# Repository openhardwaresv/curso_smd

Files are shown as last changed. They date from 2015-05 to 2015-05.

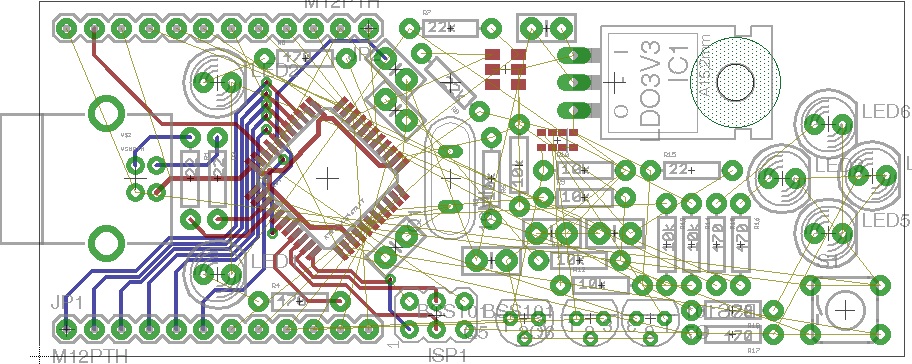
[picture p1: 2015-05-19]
dsn/auxiliar/Sensorino_PTH.jpg

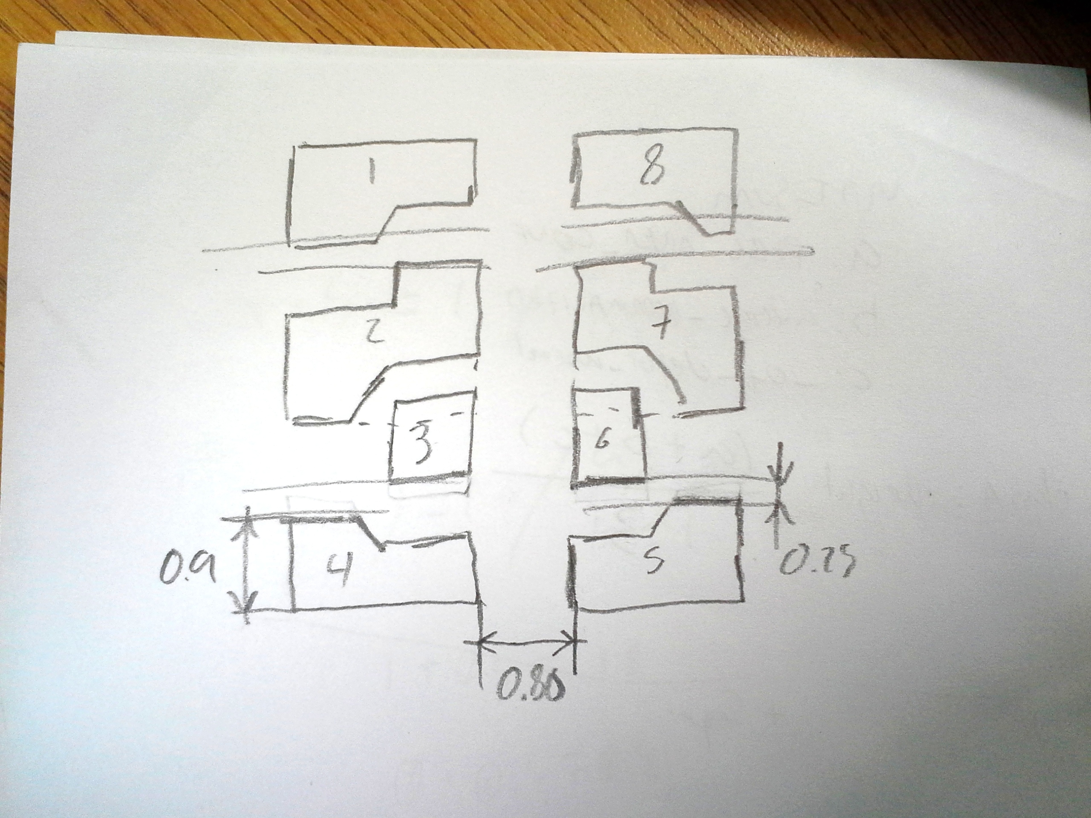
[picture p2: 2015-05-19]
dsn/auxiliar/PAD_COMBINADO.jpg

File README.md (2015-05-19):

Sensorino - Iniciandote con Componentes de Montaje Superficial
================================================================

Sensorino es una tableta electrónica programable compatible con
Arduino Leonardo impulsada por la comunidad OpenHardware.SV diseñada
en colaboración por TeUbi.co y ALSW para enseñar los fundamentos
básicos sobre el diseño de tabletas electrónicas haciendo uso de
componentes de montaje superficial.

La tableta es basada en el microcontrolador ATMega32u4 y contiene
el bootloader de Leonardo, pero además incluye sensores y LEDs
indicadores por lo que no requiere de componentes externos más que
una fuente de alimentación una vez programada.

Actualmente la tableta tiene la posibilidad de armarse utilizando el
sensor de gestos APDS-9960 o el inclinómetro sencillo RPI-1031. Estos
sensores permiten implementar aplicaciones muy sencillas que pueden
fácilmente ser demostradas con LEDs incluídos.

Al estar basada en Leonardo la tableta también permite utilizarse como
dispositivo de entrada (teclado o mouse) con lo que se le pueden dar
aplicaciones sumamente interesantes de interacción con computador.

Esta es una tableta didáctica diseñada con la idea de aprender las bases
del diseño utilizando componentes de montaje superficial por lo que se
incluye el mismo diseño eléctrico y de PCB en distintas etapas del
diseño que facilitan y sirven como guía de los productos esperados.

Últimas adiciones
=================

+ Agregado esquemá eléctrico

Costo/Lista de Materiales
=========================

Revisar archivo adjunto BOM.csv.

Pre-requisitos/Requerimientos
=============================

En función del diseño que quieras modificar puedes encontrar las fuentes
en distintas etapas. Sin embargo para seguir todo el proceso desde cero
necesitas cumplir los siguientes requerimientos:

Software:

* EAGLE Layout editor.
* IDE Arduino.
* GIT (para guardar tus avances)

Herramientas requeridas:

* Pistola de calor de temperatura y flujo regulable (Se recomienda Sparkfun 303D)
* Tercera mano
* Pinza curvada auto-blocante anti-estática
* Espátula plástica o tarjeta de vinil (para aplicar la pasta)
* Pasta para soldar libre de plomo

Construcción y uso
==================

Revisar directorio "Documentación"

Carpetas
========
* *doc*: Utiliza esta carpeta para ingresar toda la documentación que consideres
necesaria para tu proyecto. De preferencia utiliza formatos libres como "ODF"
o simples archivos de texto, si puedes crear una página web en HTML recuerda
renombrar el archivo principal como "index.html" para que pueda ser accedido
fácilmente en caso de que alguien copie esta carpeta en un servidor web.
* *src*: Coloca en esta carpeta todos los archivos de código fuente del software
de control de tu proyecto Open Hardware. Si utilizas un IDE como Eclipse o Arduino
copia dentro de src la carpeta del proyecto.
* *dsn* / *diseño*: En esta carpeta coloca todos los archivos para el diseño de tu
proyecto.
  +  *main*: Coloca en esta carpeta los archivos de diseño original que pueden
incluir, pero no limitarse a: Dibujos 2D, diseños 3D, archivos CAD, bibliotecas
de componentes, dibujos técnicos adicionales.
  +  *aux*: Coloca en esta carpeta los archivos de diseño auxiliares que ayuden
a construir tu proyecto. Los archivos de diseño secundario pueden incluír diseños
2D o 3D en formato de intercambio, dibujos técnicos adicionales, formatos listos
para manufactura, artes gráficos adicionales.
* *extra*: Esta carpeta es libre, aquí puedes colocar otros archivos que se
puedan requerir para hacer funcionar o construir tu proyecto. Un ejemplo de ello
puede ser un driver controlador de un dispositivo específico o vínculos a software
relevante, fotografías o videos.

Excepción de responsabilidades
==============================

Es recomendable que incluyas un texto como el siguiente en tus proyectos:

> El presente proyecto se comparte "tal cual" con el único objetivo de que sea útil.
El/los creadores del presente hardware y su software asociado no pueden garantizar su
correcto funcionamiento bajo ninguna circunstancia. El/Los autor/es de este proyecto
no podrá/n hacerse responsable/s de cualquier pérdida de carácter material, personal o
económico a su persona o terceros derivados de la utilización del mismo. Este proyecto
no deberá ser utilizado bajo ninguna circustancia en sistemas de carácter crítico
o sistemas de los cuales dependan vidas de personas de manera directa o indirecta.

Licenciamiento
==============

Agrega aquí la licencia que utilizas en el código fuente de tu proyecto, adicionalmente
agradeceríamos si colocas la nota de atribución de la plantilla al final.

> La plantilla de este README.md ha sido desarrollada por la comunidad openhardware.sv
con el objetivo de facilitar la documentación de proyectos. Esta plantilla está protegida
bajo la licencia CC BY, puedes modificarla y redistribuirla manteniendo esta nota de

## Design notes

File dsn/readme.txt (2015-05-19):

Archivos de diseño
==================

Encuentra los archivos de diseño de Sensorino en esta carpeta.

Archivos de diseño principal:

* main\Sensorino.sch : Archivo fuente del diagráma eléctrico para Eagle.
* main\Sensorino.brd : Archivo fuente de la tableta impresa para Eagle.

Archivos de diseño auxiliar:
* main\Sensorino_sch_print.pdf : PDF para impresión del diagrama eléctrico
* main\PAD_COMBINADO.jpg : Pad combinado para ambos sensores.

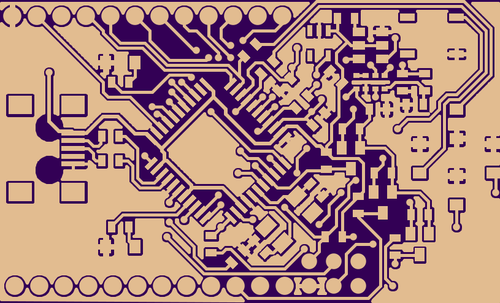
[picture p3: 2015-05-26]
dsn/auxiliar/Renders SMD/TOP_copper.png

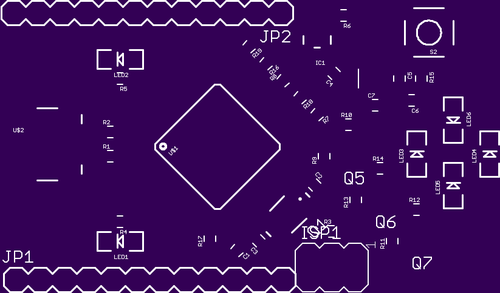
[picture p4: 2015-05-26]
dsn/auxiliar/Renders SMD/silkscreen.png

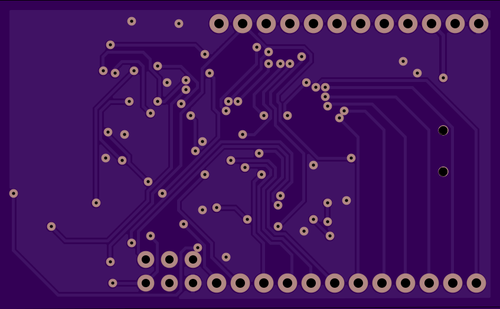
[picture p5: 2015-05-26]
dsn/auxiliar/Renders SMD/Board_Bottom.png

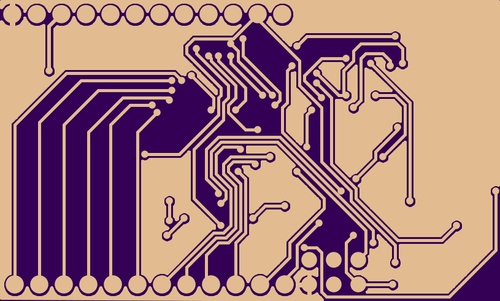
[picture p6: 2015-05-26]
dsn/auxiliar/Renders SMD/Bottom_copper.png

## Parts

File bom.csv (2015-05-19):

Part | Value | Device | Package | Description | PROD_ID | VALUE
C1 | 0.1uF | 0.1UF-50V-20%(PTH)KIT-EZ | CAP-PTH-SMALL-KIT | CAP-08370 | CAP-08370
C2 | 18pF | 0.1UF-50V-20%(PTH)KIT-EZ | CAP-PTH-SMALL-KIT | CAP-08370 | CAP-08370
C3 | 18pF | 0.1UF-50V-20%(PTH)KIT-EZ | CAP-PTH-SMALL-KIT | CAP-08370 | CAP-08370
C4 | 22pF | 0.1UF-50V-20%(PTH)KIT-EZ | CAP-PTH-SMALL-KIT | CAP-08370 | CAP-08370
C5 | 22pF | 0.1UF-50V-20%(PTH)KIT-EZ | CAP-PTH-SMALL-KIT | CAP-08370 | CAP-08370
C6 | 22pF | 0.1UF-50V-20%(PTH)KIT-EZ | CAP-PTH-SMALL-KIT | CAP-08370 | CAP-08370
C7 | 22pF | 0.1UF-50V-20%(PTH)KIT-EZ | CAP-PTH-SMALL-KIT | CAP-08370 | CAP-08370
IC1 | LDO3V3 | 78XXL | 78XXL | VOLTAGE REGULATOR
ISP1 | AVRISP-6 | AVRISP-6 | AVRISP | AVR ISP HEADER
JP1 | M12PTH | M12PTH | 1X12 | Header 12
JP2 | M12PTH | M12PTH | 1X12 | Header 12
LED1 |  | LED5MM | LED5MM | LEDs
LED2 |  | LED5MM | LED5MM | LEDs
LED3 |  | LED5MM | LED5MM | LEDs
LED4 |  | LED5MM | LED5MM | LEDs
LED5 |  | LED5MM | LED5MM | LEDs
LED6 |  | LED5MM | LED5MM | LEDs
Q1 |  | XTAL/S | QS | CRYSTAL
Q2 |  | MOSFET-NGDS_TO220V | TO220V | N-Channel Mosfet
Q3 |  | MOSFET-NGDS_TO220V | TO220V | N-Channel Mosfet
Q4 |  | MOSFET-NGDS_TO220V | TO220V | N-Channel Mosfet
R1 | 22 | RESISTORAXIAL-0.3 | AXIAL-0.3 | Resistor
R2 | 22 | RESISTORAXIAL-0.3 | AXIAL-0.3 | Resistor
R3 | 10k | RESISTORAXIAL-0.3 | AXIAL-0.3 | Resistor
R4 | 470 | RESISTORAXIAL-0.3 | AXIAL-0.3 | Resistor
R5 | 470 | RESISTORAXIAL-0.3 | AXIAL-0.3 | Resistor
R6 | 10k | RESISTORAXIAL-0.3 | AXIAL-0.3 | Resistor
R7 | 22k | RESISTORAXIAL-0.3 | AXIAL-0.3 | Resistor
R8 | 22k | RESISTORAXIAL-0.3 | AXIAL-0.3 | Resistor
R9 | 10k | RESISTORAXIAL-0.3 | AXIAL-0.3 | Resistor
R10 | 10k | RESISTORAXIAL-0.3 | AXIAL-0.3 | Resistor
R11 | 10k | RESISTORAXIAL-0.3 | AXIAL-0.3 | Resistor
R12 | 10k | RESISTORAXIAL-0.3 | AXIAL-0.3 | Resistor
R13 | 10k | RESISTORAXIAL-0.3 | AXIAL-0.3 | Resistor
R14 | 10k | RESISTORAXIAL-0.3 | AXIAL-0.3 | Resistor
R15 | 22 | RESISTORAXIAL-0.3 | AXIAL-0.3 | Resistor
R16 | 470 | RESISTORAXIAL-0.3 | AXIAL-0.3 | Resistor
R17 | 470 | RESISTORAXIAL-0.3 | AXIAL-0.3 | Resistor
R18 | 470 | RESISTORAXIAL-0.3 | AXIAL-0.3 | Resistor
R19 | 470 | RESISTORAXIAL-0.3 | AXIAL-0.3 | Resistor
S1 |  | TAC_SWITCHPTH | TACTILE-PTH | Momentary Switch
U$1 | ATMEGA32U4TQFP | ATMEGA32U4TQFP | SPARKFUN-DIGITALIC_TQFP44 | Atmel 44-pin 8-bit Microcontroller with 32KBytes of ISP Flash and USB Controller -----
U$2 | USBPTH | USBPTH | USB-B-PTH | USB Connectors | CONN-08278 | USB-B
U$3 | RPI-1031 | RPI-1031 | RPI-1031
U$4 | APDS-9960 | APDS-9960 | APDS-9960

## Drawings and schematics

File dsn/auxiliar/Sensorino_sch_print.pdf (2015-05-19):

5V470

S1

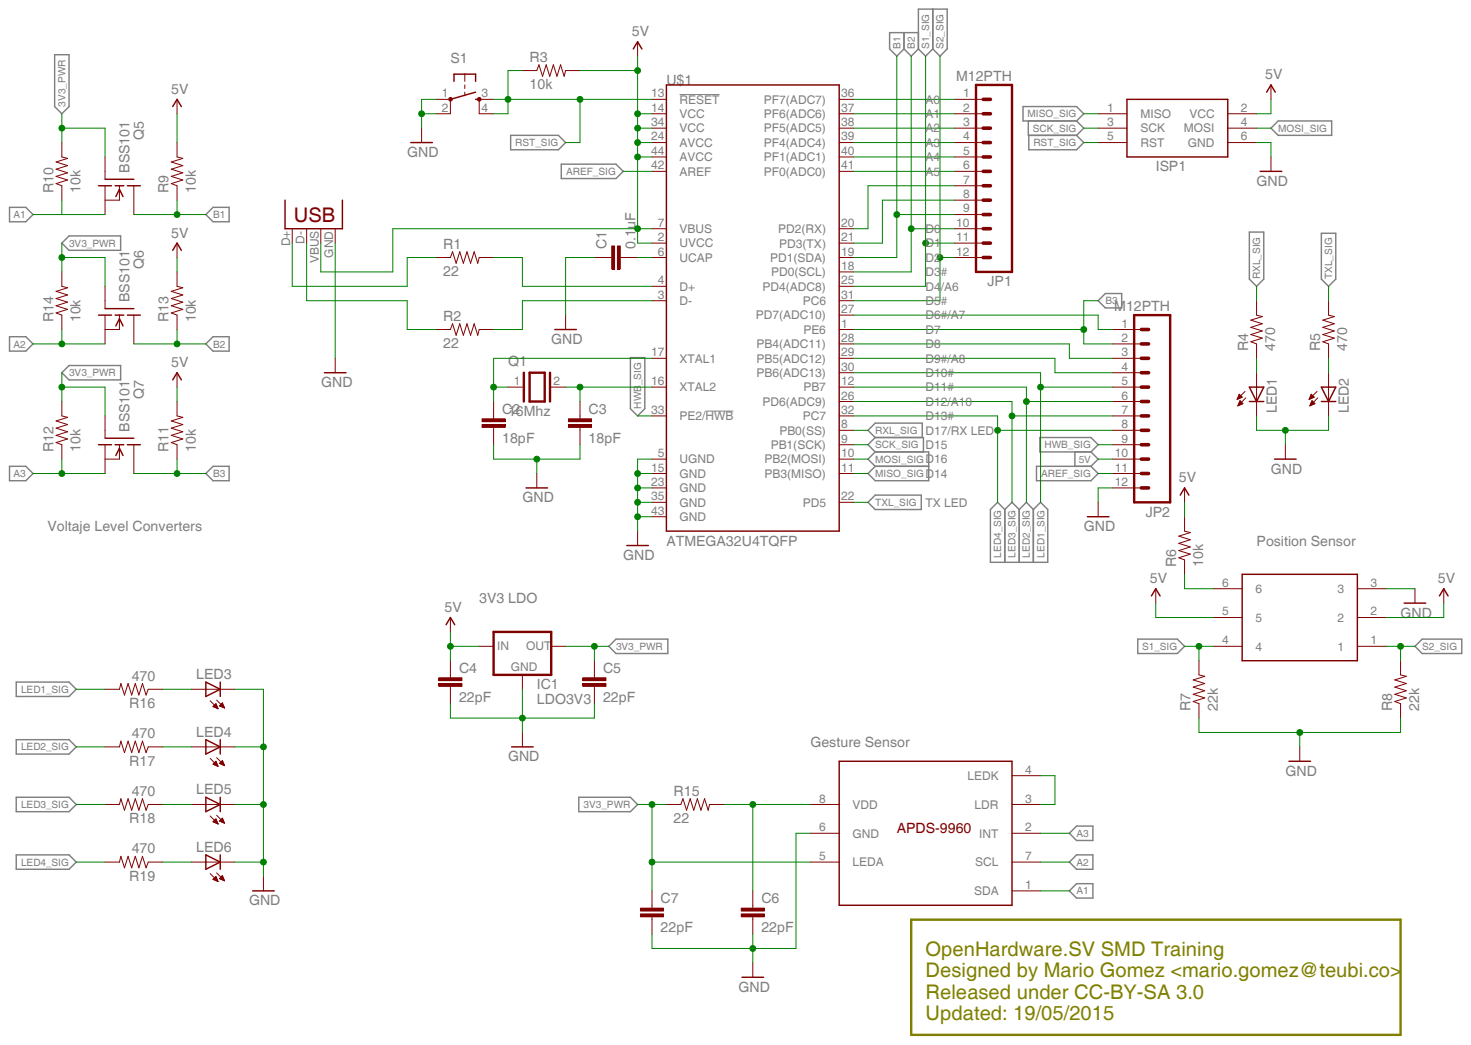
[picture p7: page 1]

OpenHardware.SV SMD Training
Designed by Mario Gomez <mario.gomez@teubi.co>
Released under CC-BY-SA 3.0
Updated: 19/05/2015

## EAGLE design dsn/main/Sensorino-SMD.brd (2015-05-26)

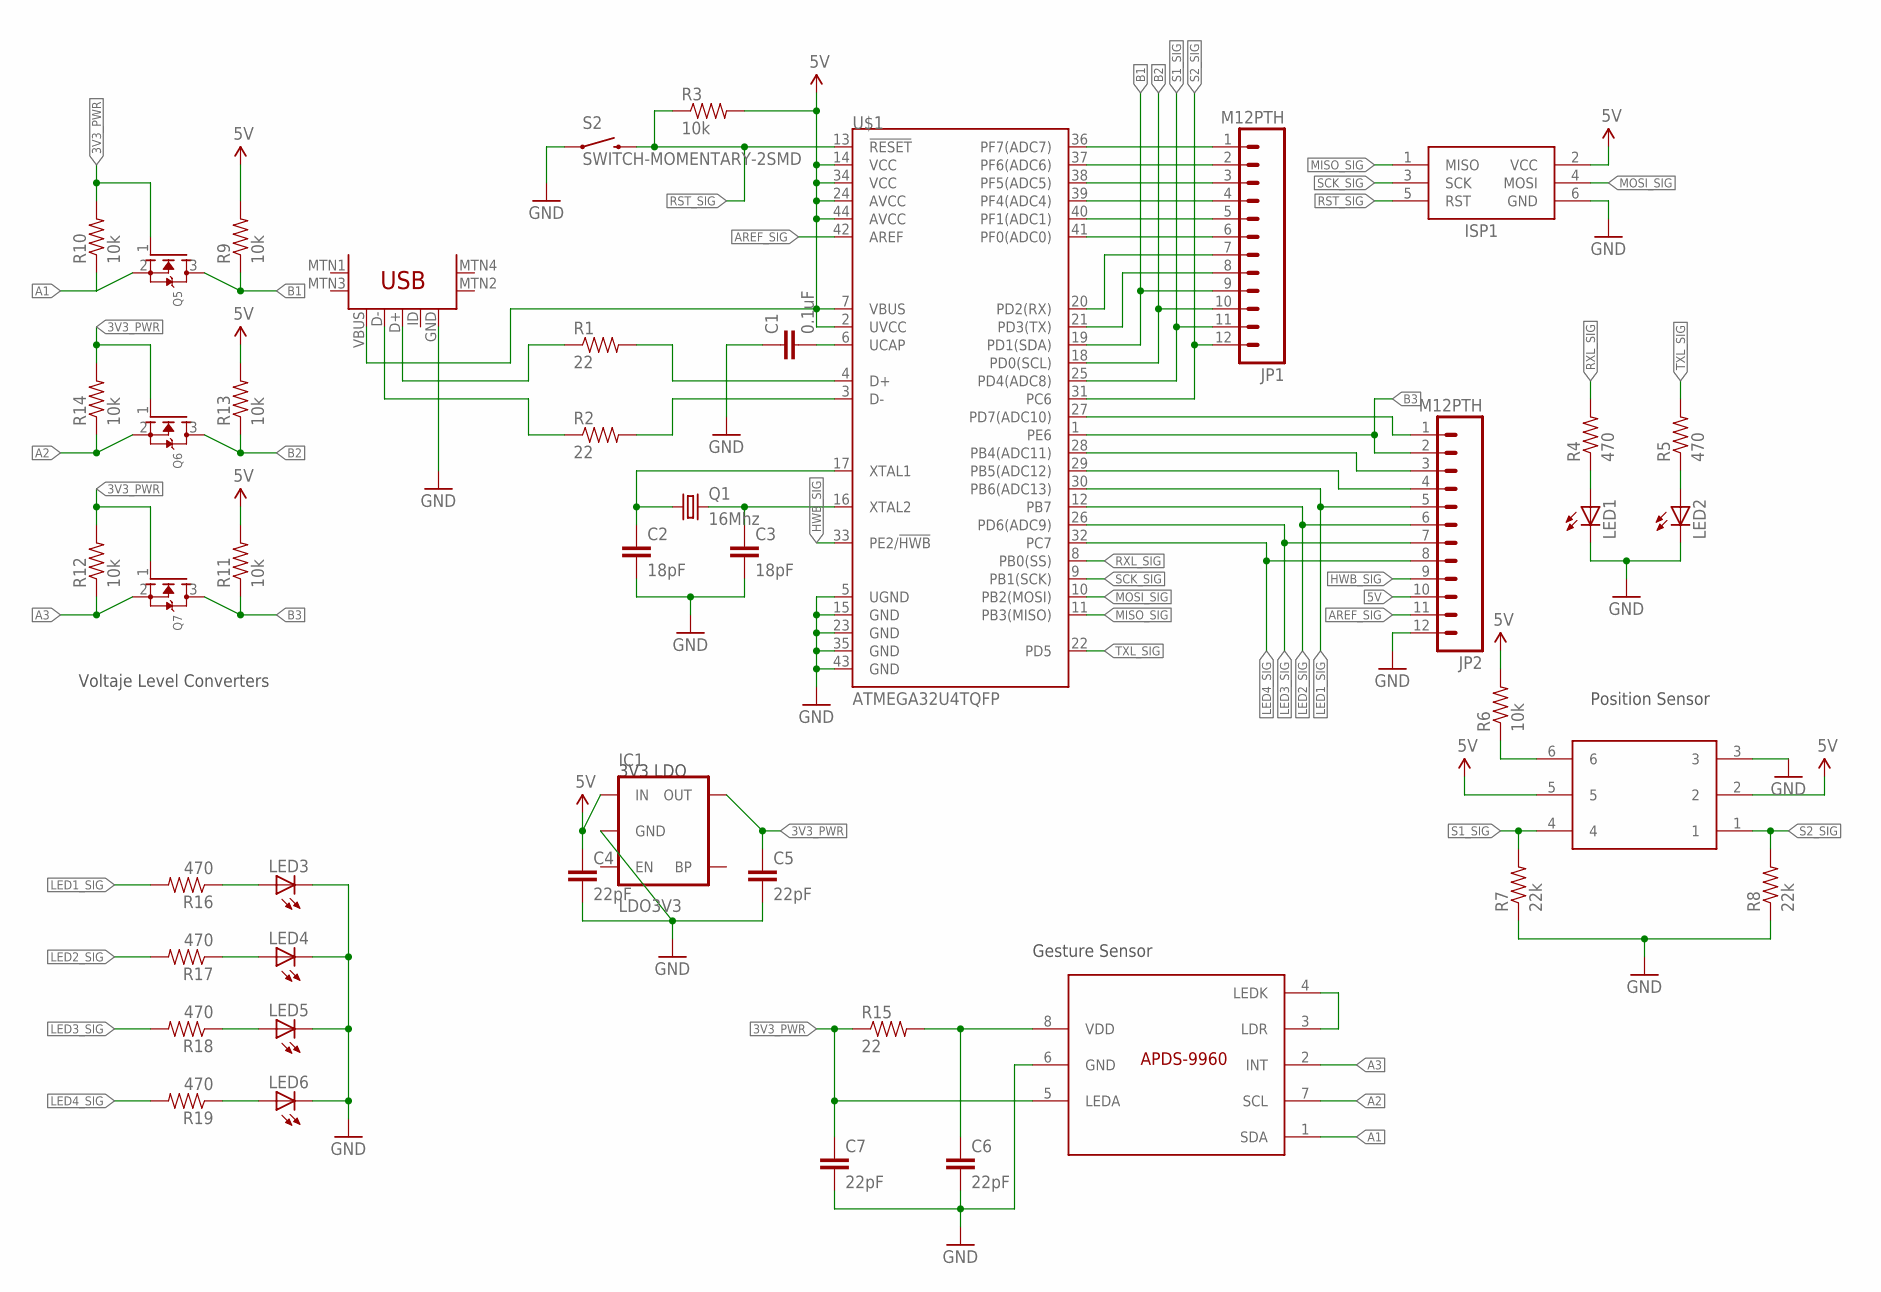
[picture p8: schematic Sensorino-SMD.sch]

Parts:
C1: 0.1uF; 0805
C2, C3: 18pF; 0805
C4, C5, C6, C7: 22pF; 0805
IC1: LDO3V3; SOT23-5
ISP1: AVRISP-6; AVRISP
JP1, JP2: M12PTH; 1X12
LED1, LED2, LED3, LED4, LED5, LED6: LED-WHITE; LED-1206
Q1: 16Mhz; CTS406
Q5, Q6, Q7: MOSFET-NREFLOW; SOT23
R1, R2, R15: 22; 0805
R3, R6, R9, R10, R11, R12, R13, R14: 10k; 0805
R4, R5, R16, R17, R18, R19: 470; 0805
R7, R8: 22k; 0805
S2: SWITCH-MOMENTARY-2SMD; TACTILE_SWITCH_SMD
U$1: ATMEGA32U4TQFP; SPARKFUN-DIGITALIC_TQFP44
U$2: USB-MINIB-5PIN; USB-MINIB
U$3: RPI-1031
U$4: APDS-9960

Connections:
3V3_PWR: C5.1, C7.1, IC1.5 (OUT), Q5.1 (G), Q6.1 (G), Q7.1 (G), R10.2, R12.2, R14.2, R15.1, U$4.5 (LEDA)
5V: C4.1, IC1.1 (IN), ISP1.2 (VCC), JP2.10, R3.2, R6.2, R9.2, R11.2, R13.2, U$1.2 (UVCC), U$1.7 (VBUS), U$1.14 (VCC), U$1.24 (AVCC), U$1.34 (VCC), U$1.44 (AVCC), U$2.VBUS, U$3.2, U$3.5
A1: Q5.2 (S), R10.1, U$4.1 (SDA)
A2: Q6.2 (S), R14.1, U$4.7 (SCL)
A3: Q7.2 (S), R12.1, U$4.2 (INT)
AREF_SIG: JP2.11, U$1.42 (AREF)
B1: JP1.9, Q5.3 (D), R9.1, U$1.19 (PD1(SDA))
B2: JP1.10, Q6.3 (D), R13.1, U$1.18 (PD0(SCL))
B3: JP2.2, Q7.3 (D), R11.1, U$1.1 (PE6)
D_USBD+: R2.1, U$2.D-
D_USBD-: R1.1, U$2.D+
D_USBRD+: R2.2, U$1.3 (D-)
D_USBRD-: R1.2, U$1.4 (D+)
GND: C1.1, C2.2, C3.2, C4.2, C5.2, C6.2, C7.2, IC1.2 (GND), ISP1.6 (GND), JP2.12, LED1.C, LED2.C, LED3.C, LED4.C, LED5.C, LED6.C, R7.1, R8.1, S2.1, U$1.5 (UGND), U$1.15 (GND), U$1.23 (GND), U$1.35 (GND), U$1.43 (GND), U$2.GND, U$3.3, U$4.6 (GND)
HWB_SIG: JP2.9, U$1.33 (PE2/!HWB)
LED1_SIG: JP2.5, R16.2, U$1.30 (PB6(ADC13))
LED2_SIG: JP2.6, R17.2, U$1.12 (PB7)
LED3_SIG: JP2.7, R18.2, U$1.26 (PD6(ADC9))
LED4_SIG: JP2.8, R19.2, U$1.32 (PC7)
MISO_SIG: ISP1.1 (MISO), U$1.11 (PB3(MISO))
MOSI_SIG: ISP1.4 (MOSI), U$1.10 (PB2(MOSI))
unnamed: JP2.1, U$1.27 (PD7(ADC10))
unnamed: C1.2, U$1.6 (UCAP)
unnamed: C3.1, Q1.3 (2), U$1.16 (XTAL2)
unnamed: C2.1, Q1.1, U$1.17 (XTAL1)
unnamed: LED3.A, R16.1
unnamed: JP2.3, U$1.28 (PB4(ADC11))
unnamed: LED1.A, R4.1
unnamed: LED2.A, R5.1
unnamed: JP1.1, U$1.36 (PF7(ADC7))
unnamed: JP1.2, U$1.37 (PF6(ADC6))
unnamed: JP1.3, U$1.38 (PF5(ADC5))
unnamed: JP1.4, U$1.39 (PF4(ADC4))
unnamed: JP1.5, U$1.40 (PF1(ADC1))
unnamed: JP1.6, U$1.41 (PF0(ADC0))
unnamed: JP1.7, U$1.20 (PD2(RX))
unnamed: JP1.8, U$1.21 (PD3(TX))
unnamed: LED4.A, R17.1
unnamed: LED5.A, R18.1
unnamed: LED6.A, R19.1
unnamed: JP2.4, U$1.29 (PB5(ADC12))
unnamed: R6.1, U$3.6
unnamed: U$4.3 (LDR), U$4.4 (LEDK)
unnamed: C6.1, R15.2, U$4.8 (VDD)
RST_SIG: ISP1.5 (RST), R3.1, S2.3 (2), U$1.13 (!RESET)
RXL_SIG: R4.2, U$1.8 (PB0(SS))
S1_SIG: JP1.11, R7.2, U$1.25 (PD4(ADC8)), U$3.4
S2_SIG: JP1.12, R8.2, U$1.31 (PC6), U$3.1
SCK_SIG: ISP1.3 (SCK), U$1.9 (PB1(SCK))
TXL_SIG: R5.2, U$1.22 (PD5)

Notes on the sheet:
Voltaje Level Converters
3V3 LDO
Gesture Sensor
Position Sensor

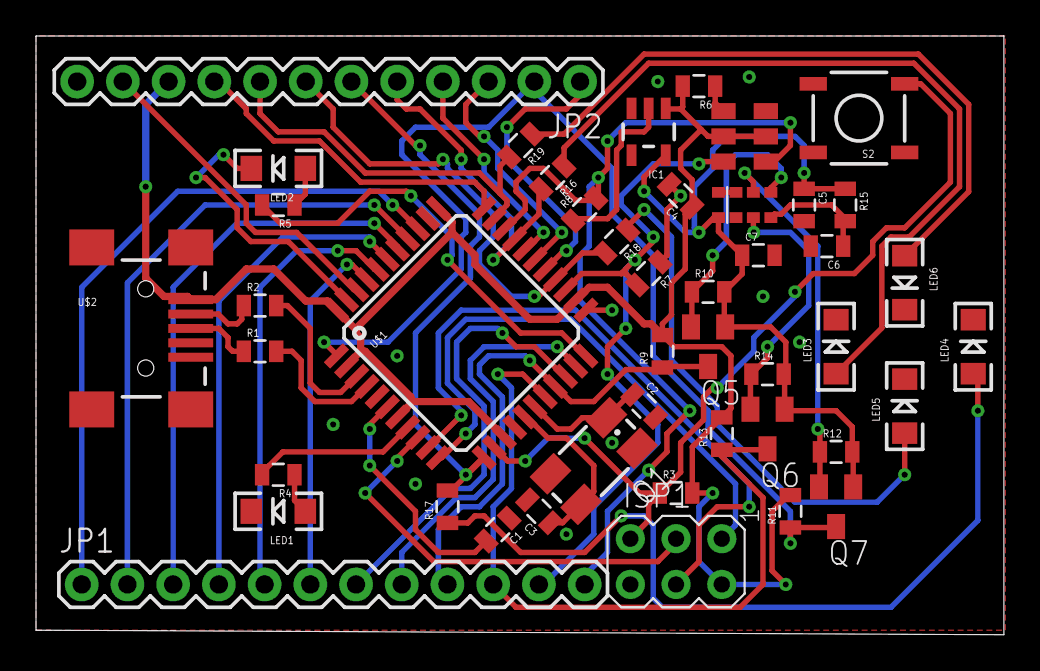
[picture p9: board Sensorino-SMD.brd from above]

Board: 2 copper layers, 53.8 x 33.3 mm, 45 parts (0 on the bottom side), 50 nets.

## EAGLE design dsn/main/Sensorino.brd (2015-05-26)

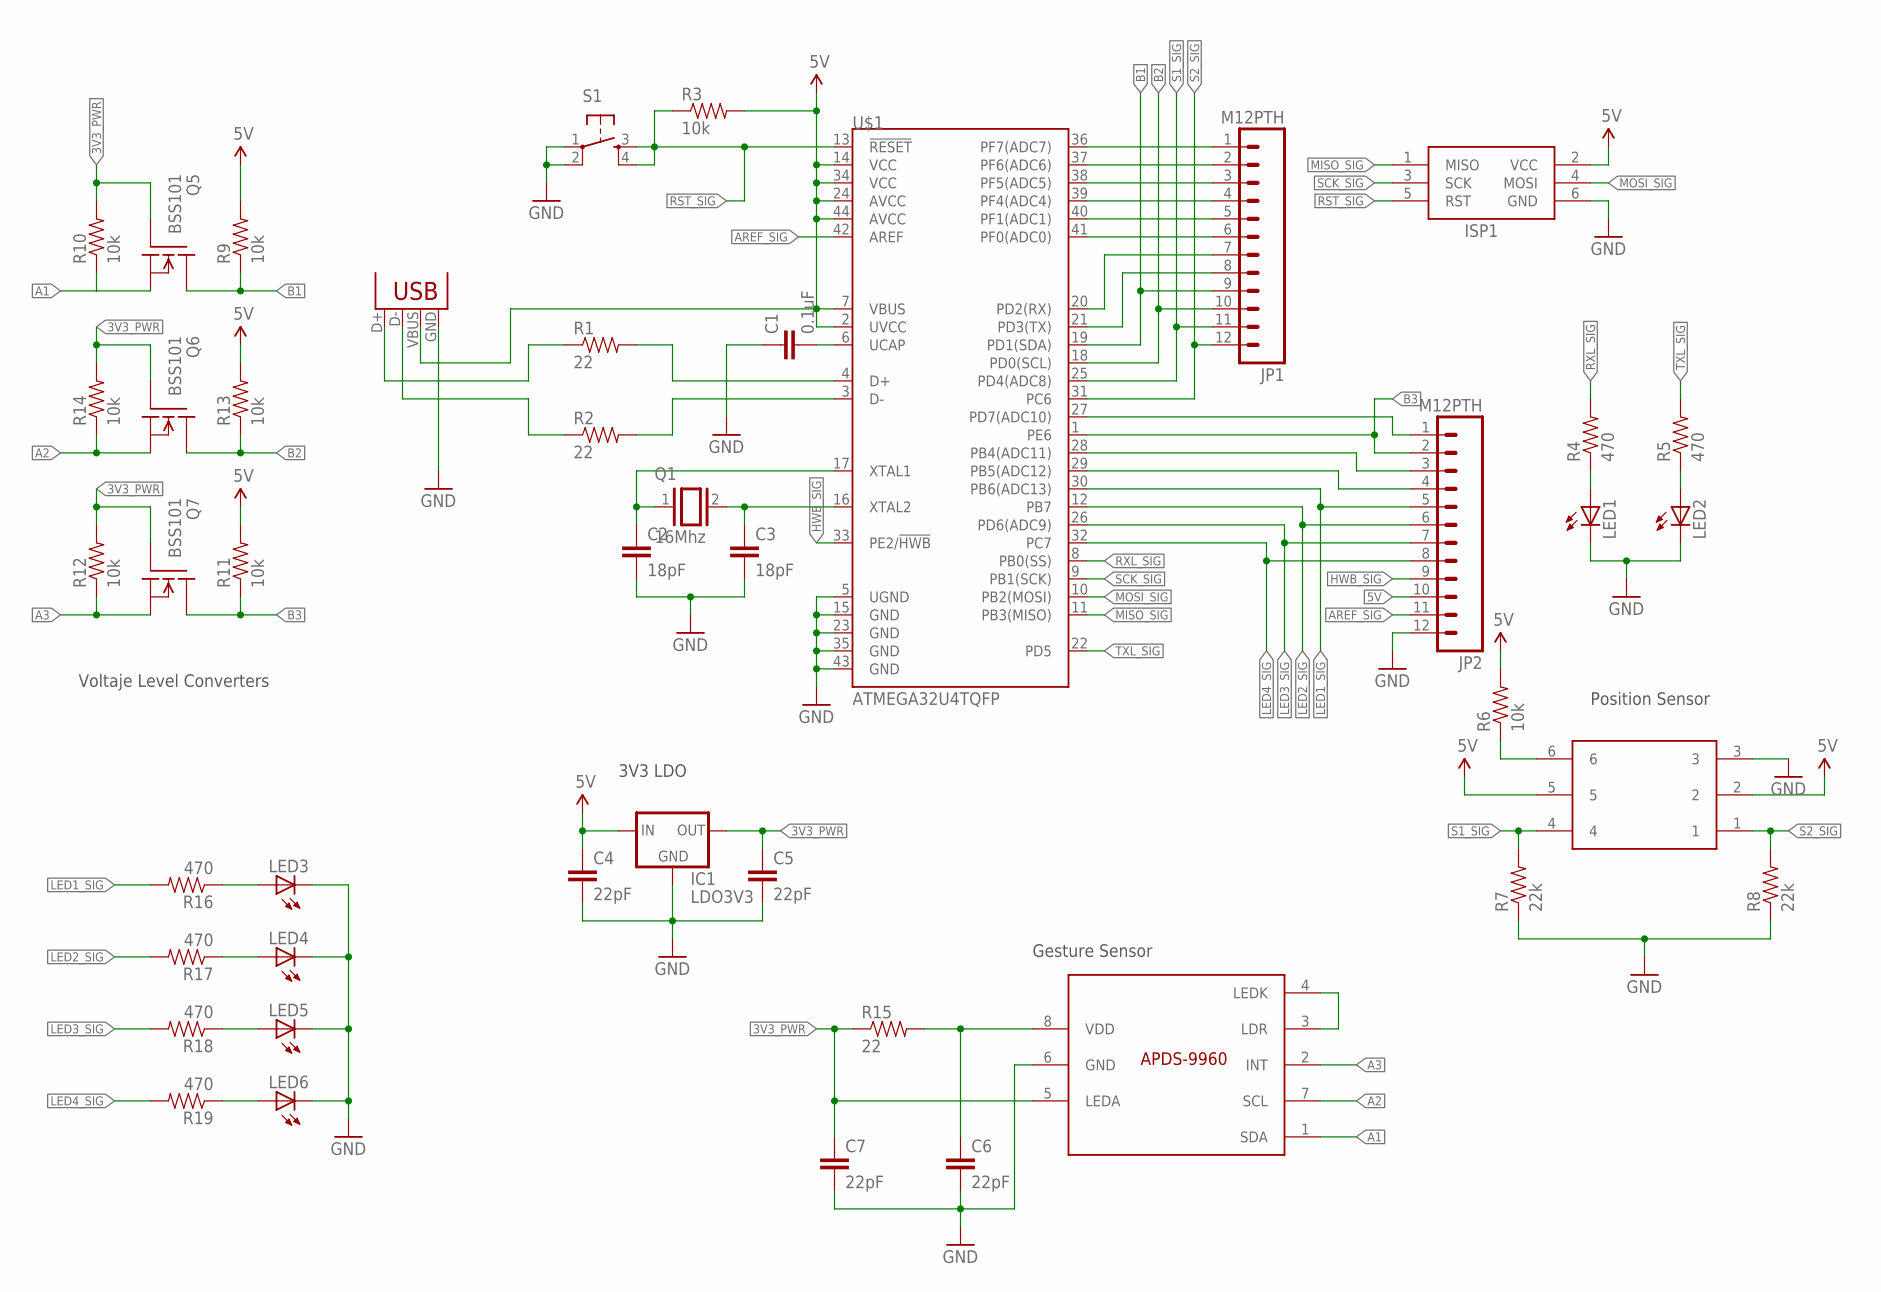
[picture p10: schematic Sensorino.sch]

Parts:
C1: 0.1uF; CAP-PTH-SMALL-KIT
C2, C3: 18pF; CAP-PTH-SMALL-KIT
C4, C5, C6, C7: 22pF; CAP-PTH-SMALL-KIT
IC1: LDO3V3; 78XXL
ISP1: AVRISP-6; AVRISP
JP1, JP2: M12PTH; 1X12
LED1, LED2, LED3, LED4, LED5, LED6: LED5MM
Q1: 16Mhz; QS
Q5, Q6, Q7: BSS101; TO92
R1, R2, R15: 22; AXIAL-0.3
R3, R6, R9, R10, R11, R12, R13, R14: 10k; AXIAL-0.3
R4, R5, R16, R17, R18, R19: 470; AXIAL-0.3
R7, R8: 22k; AXIAL-0.3
S1: TAC_SWITCHPTH; TACTILE-PTH
U$1: ATMEGA32U4TQFP; SPARKFUN-DIGITALIC_TQFP44
U$2: USBPTH; USB-B-PTH
U$3: RPI-1031
U$4: APDS-9960

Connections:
3V3_PWR: C5.1, C7.1, IC1.OUT, Q5.2 (G), Q6.2 (G), Q7.2 (G), R10.P$2 (2), R12.P$2 (2), R14.P$2 (2), R15.P$1 (1), U$4.5 (LEDA)
5V: C4.1, IC1.IN, ISP1.2 (VCC), JP2.10, R3.P$2 (2), R6.P$2 (2), R9.P$2 (2), R11.P$2 (2), R13.P$2 (2), U$1.2 (UVCC), U$1.7 (VBUS), U$1.14 (VCC), U$1.24 (AVCC), U$1.34 (VCC), U$1.44 (AVCC), U$2.VBUS, U$3.2, U$3.5
A1: Q5.1 (S), R10.P$1 (1), U$4.1 (SDA)
A2: Q6.1 (S), R14.P$1 (1), U$4.7 (SCL)
A3: Q7.1 (S), R12.P$1 (1), U$4.2 (INT)
AREF_SIG: JP2.11, U$1.42 (AREF)
B1: JP1.9, Q5.3 (D), R9.P$1 (1), U$1.19 (PD1(SDA))
B2: JP1.10, Q6.3 (D), R13.P$1 (1), U$1.18 (PD0(SCL))
B3: JP2.2, Q7.3 (D), R11.P$1 (1), U$1.1 (PE6)
GND: C1.1, C2.2, C3.2, C4.2, C5.2, C6.2, C7.2, IC1.GND, ISP1.6 (GND), JP2.12, LED1.K (C), LED2.K (C), LED3.K (C), LED4.K (C), LED5.K (C), LED6.K (C), R7.P$1 (1), R8.P$1 (1), S1.1, S1.2, U$1.5 (UGND), U$1.15 (GND), U$1.23 (GND), U$1.35 (GND), U$1.43 (GND), U$2.GND, U$3.3, U$4.6 (GND)
HWB_SIG: JP2.9, U$1.33 (PE2/!HWB)
LED1_SIG: JP2.5, R16.P$2 (2), U$1.30 (PB6(ADC13))
LED2_SIG: JP2.6, R17.P$2 (2), U$1.12 (PB7)
LED3_SIG: JP2.7, R18.P$2 (2), U$1.26 (PD6(ADC9))
LED4_SIG: JP2.8, R19.P$2 (2), U$1.32 (PC7)
MISO_SIG: ISP1.1 (MISO), U$1.11 (PB3(MISO))
MOSI_SIG: ISP1.4 (MOSI), U$1.10 (PB2(MOSI))
unnamed: R2.P$2 (2), U$1.3 (D-)
unnamed: R1.P$2 (2), U$1.4 (D+)
unnamed: R1.P$1 (1), U$2.D+
unnamed: R2.P$1 (1), U$2.D-
unnamed: JP2.1, U$1.27 (PD7(ADC10))
unnamed: C1.2, U$1.6 (UCAP)
unnamed: C3.1, Q1.2, U$1.16 (XTAL2)
unnamed: C2.1, Q1.1, U$1.17 (XTAL1)
unnamed: LED3.A, R16.P$1 (1)
unnamed: JP2.3, U$1.28 (PB4(ADC11))
unnamed: LED1.A, R4.P$1 (1)
unnamed: LED2.A, R5.P$1 (1)
unnamed: JP1.1, U$1.36 (PF7(ADC7))
unnamed: JP1.2, U$1.37 (PF6(ADC6))
unnamed: JP1.3, U$1.38 (PF5(ADC5))
unnamed: JP1.4, U$1.39 (PF4(ADC4))
unnamed: JP1.5, U$1.40 (PF1(ADC1))
unnamed: JP1.6, U$1.41 (PF0(ADC0))
unnamed: JP1.7, U$1.20 (PD2(RX))
unnamed: JP1.8, U$1.21 (PD3(TX))
unnamed: LED4.A, R17.P$1 (1)
unnamed: LED5.A, R18.P$1 (1)
unnamed: LED6.A, R19.P$1 (1)
unnamed: JP2.4, U$1.29 (PB5(ADC12))
unnamed: R6.P$1 (1), U$3.6
unnamed: U$4.3 (LDR), U$4.4 (LEDK)
unnamed: C6.1, R15.P$2 (2), U$4.8 (VDD)
RST_SIG: ISP1.5 (RST), R3.P$1 (1), S1.3, S1.4, U$1.13 (!RESET)
RXL_SIG: R4.P$2 (2), U$1.8 (PB0(SS))
S1_SIG: JP1.11, R7.P$2 (2), U$1.25 (PD4(ADC8)), U$3.4
S2_SIG: JP1.12, R8.P$2 (2), U$1.31 (PC6), U$3.1
SCK_SIG: ISP1.3 (SCK), U$1.9 (PB1(SCK))
TXL_SIG: R5.P$2 (2), U$1.22 (PD5)

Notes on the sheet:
Voltaje Level Converters
3V3 LDO
Gesture Sensor
Position Sensor

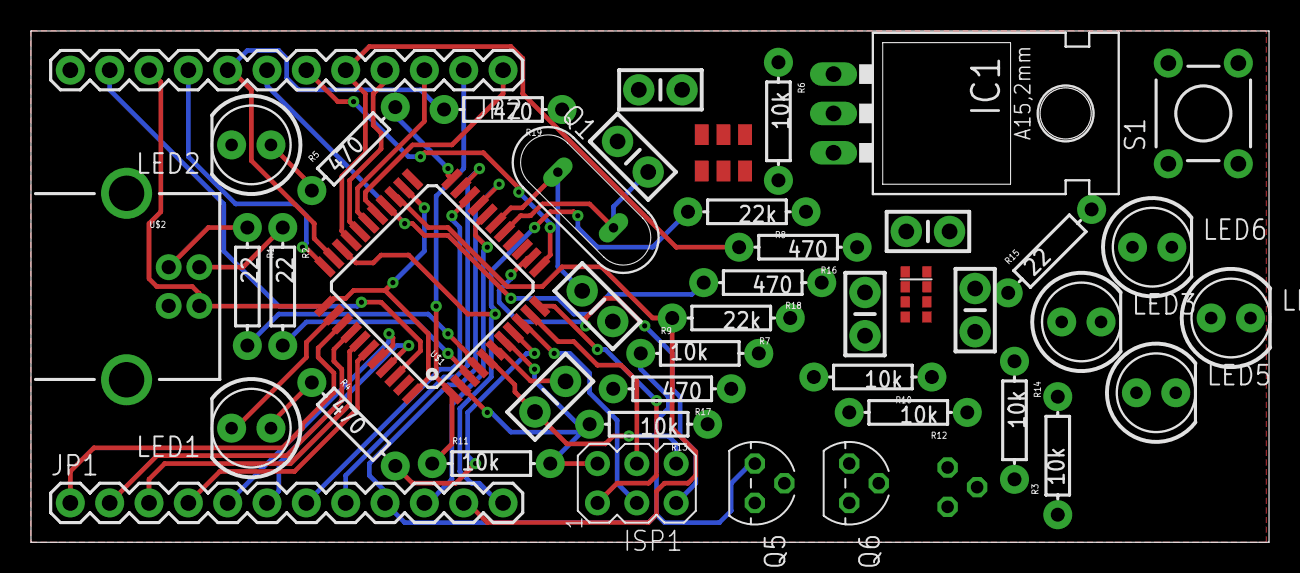
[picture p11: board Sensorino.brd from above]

Board: 2 copper layers, 79.9 x 33.0 mm, 45 parts (1 on the bottom side), 50 nets.

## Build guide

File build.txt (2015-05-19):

Construyendo mi proyecto
========================

Coloca en este archivo instrucciones detalladas sobre la construcción del hardware
que has desarrollado. Es recomendable que coloques las instrucciones detalladas
por pasos como se ejemplifica a continuación

Paso 1 - Desempaquetando
========================

Saca los componentes de las bolsas y colócalos en la mesa, cuéntalos en base
al archivo bom.txt  y revisa que todo se encuentre en orden.

Paso 2 - Conectando
===================

Conecta a la breadboard una resistencia y un LED de 330Ohm en serie.
Luego conecta la línea 13 del Arduino UNO a la resistencia.

Paso 3 - Construyendo el código
===============================

Conecta tu arduino a la PC y abre el Sketch en la carpeta src/Test/Test.ino
y súbelo a tu Arduino.

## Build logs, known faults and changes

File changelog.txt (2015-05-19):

201505191217:

+Modificado formato a plantilla OSHW

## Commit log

2015-05-19 Values corrected for R7 & R8
    [Capacitacion_SMD.brd, Capacitacion_SMD.sch]
2015-05-19 Added indicator LEDs
    [Capacitacion_SMD.brd, Capacitacion_SMD.sch]
2015-05-19 Reestructurado formato de plantilla.
    [bom.csv, bom.ods]
2015-05-19 Added PTH render
    [Sensorino.brd, Sensorino.sch]
2015-05-19 Mosfet changed to a more-acceptable model
    [Sensorino.brd, Sensorino.sch]
2015-05-19 Modified PTH PCB Layout
    [Sensorino.brd]
2015-05-26 Added SMD version
    [Sensorino-SMD.brd, Sensorino-SMD.sch, Sensorino.brd]

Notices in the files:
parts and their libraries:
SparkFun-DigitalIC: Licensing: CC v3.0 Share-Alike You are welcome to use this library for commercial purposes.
